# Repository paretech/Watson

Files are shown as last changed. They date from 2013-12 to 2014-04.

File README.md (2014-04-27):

Watson
======

Watson is a relatively simple RF power meter based on the "120 dB Measurement System" outlined in the Analog Devices (AD) AD8307 data sheet. Watson has a narrow and fixed measurement band centered on 10.7 MHz and was developed as the detector for a low cost spectrum analyzer design. 

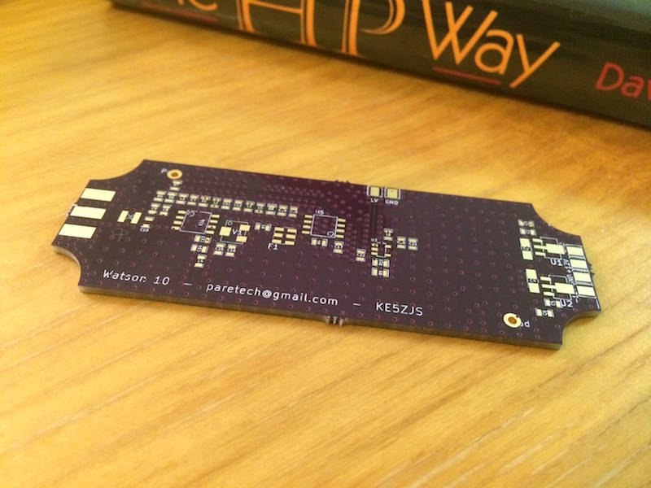
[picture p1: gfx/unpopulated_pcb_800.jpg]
Un-Populated Watson PCB


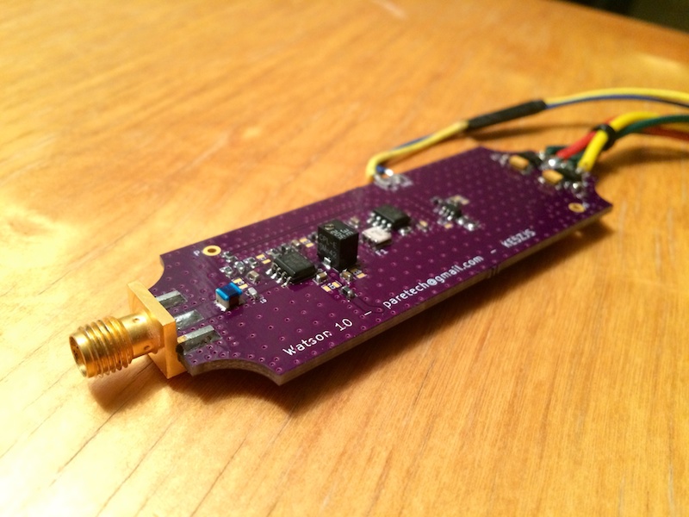
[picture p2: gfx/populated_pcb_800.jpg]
Populated Watson PCB


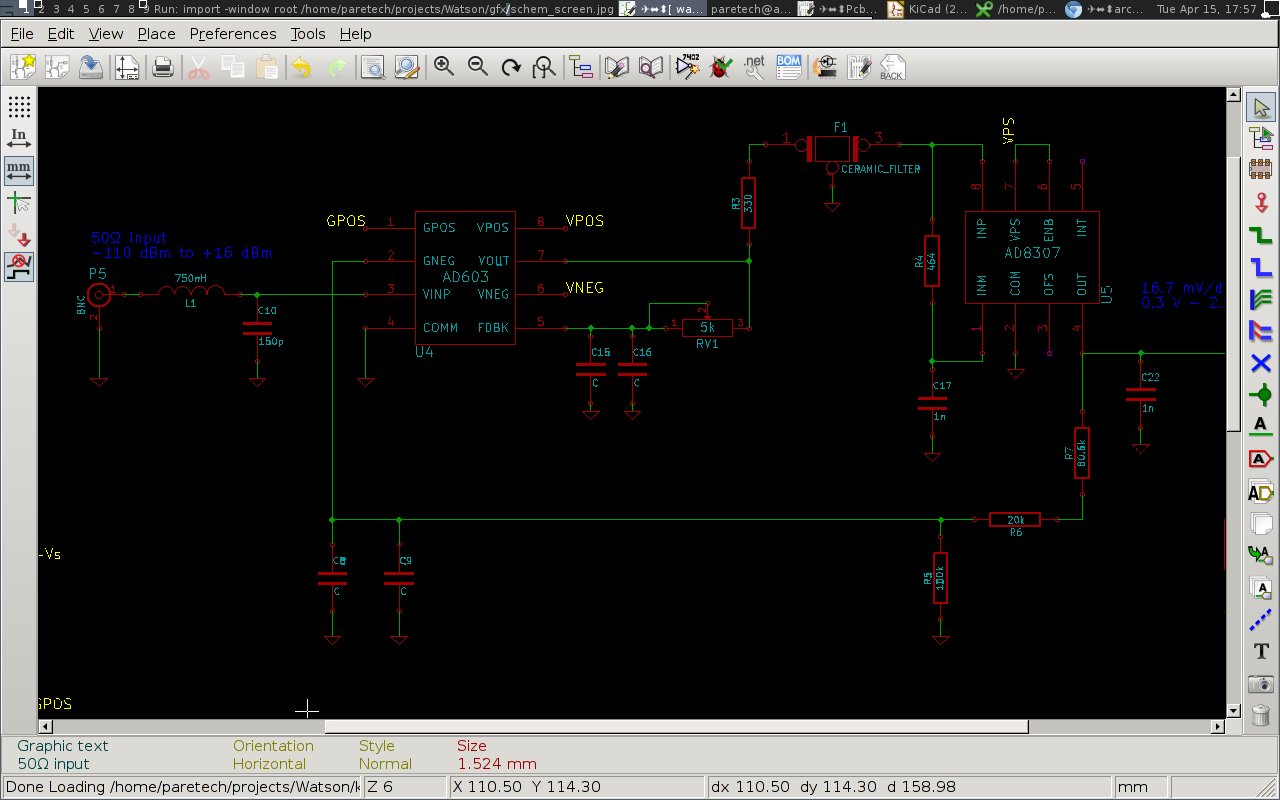
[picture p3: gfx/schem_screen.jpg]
Screen grab of Watson's Schematic


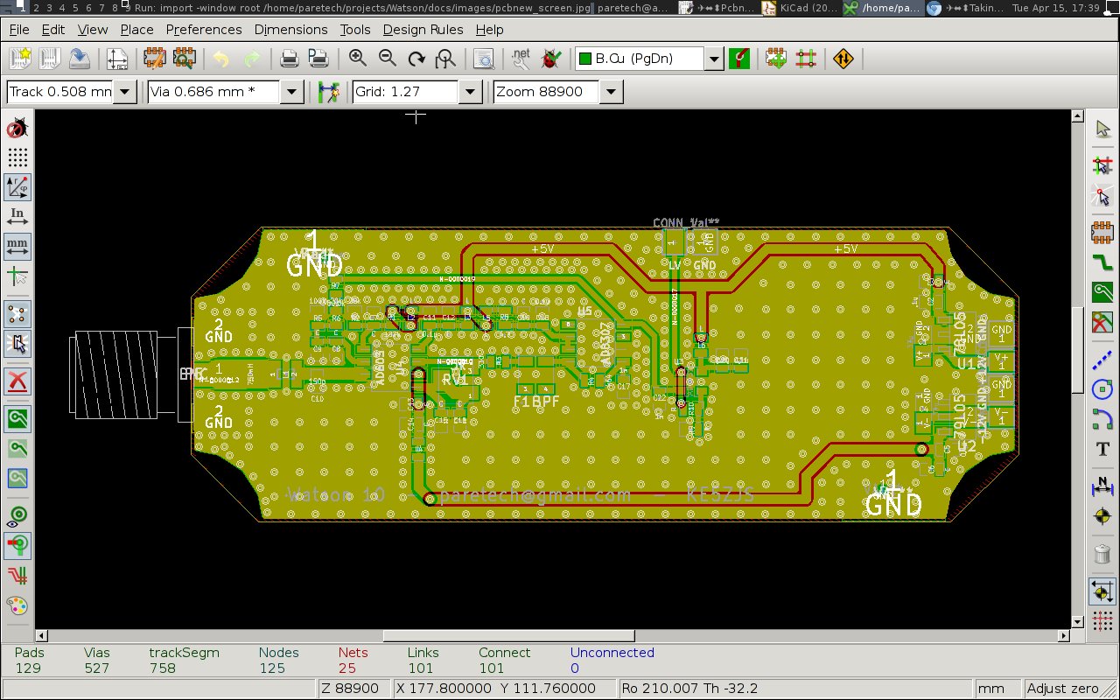
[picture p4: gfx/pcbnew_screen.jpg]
Snapshot of Watson's Board Layout


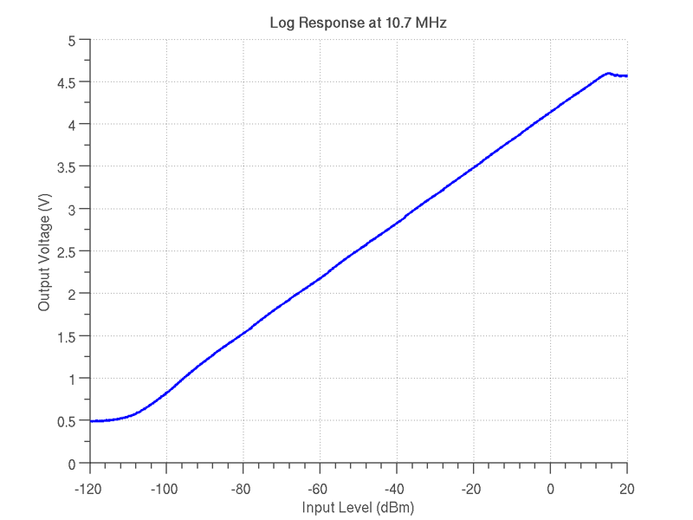
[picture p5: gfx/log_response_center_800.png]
Log Response at 10.7 MHz


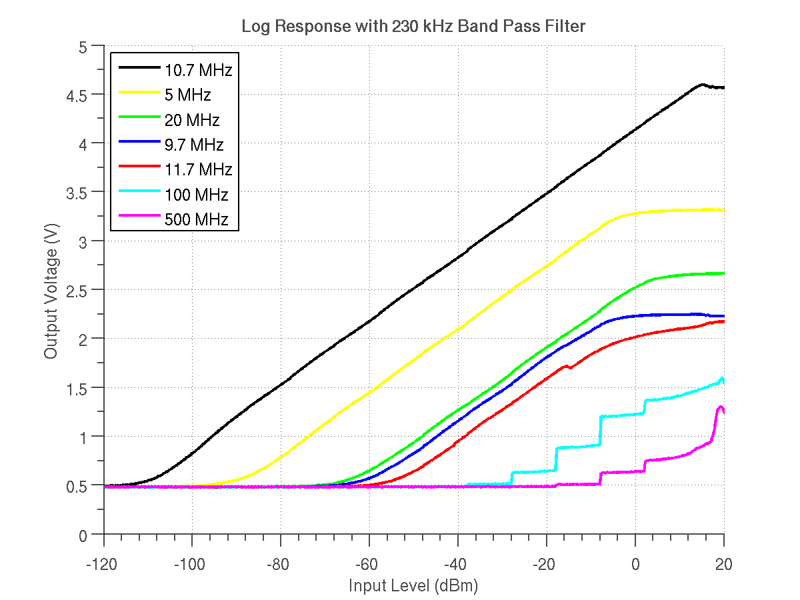
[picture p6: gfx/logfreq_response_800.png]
Log Frequency Response


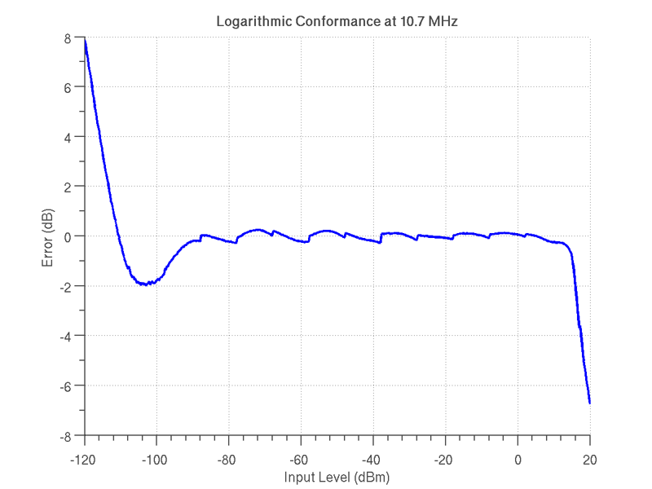
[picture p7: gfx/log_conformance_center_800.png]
Log Conformance at 10.7 MHz


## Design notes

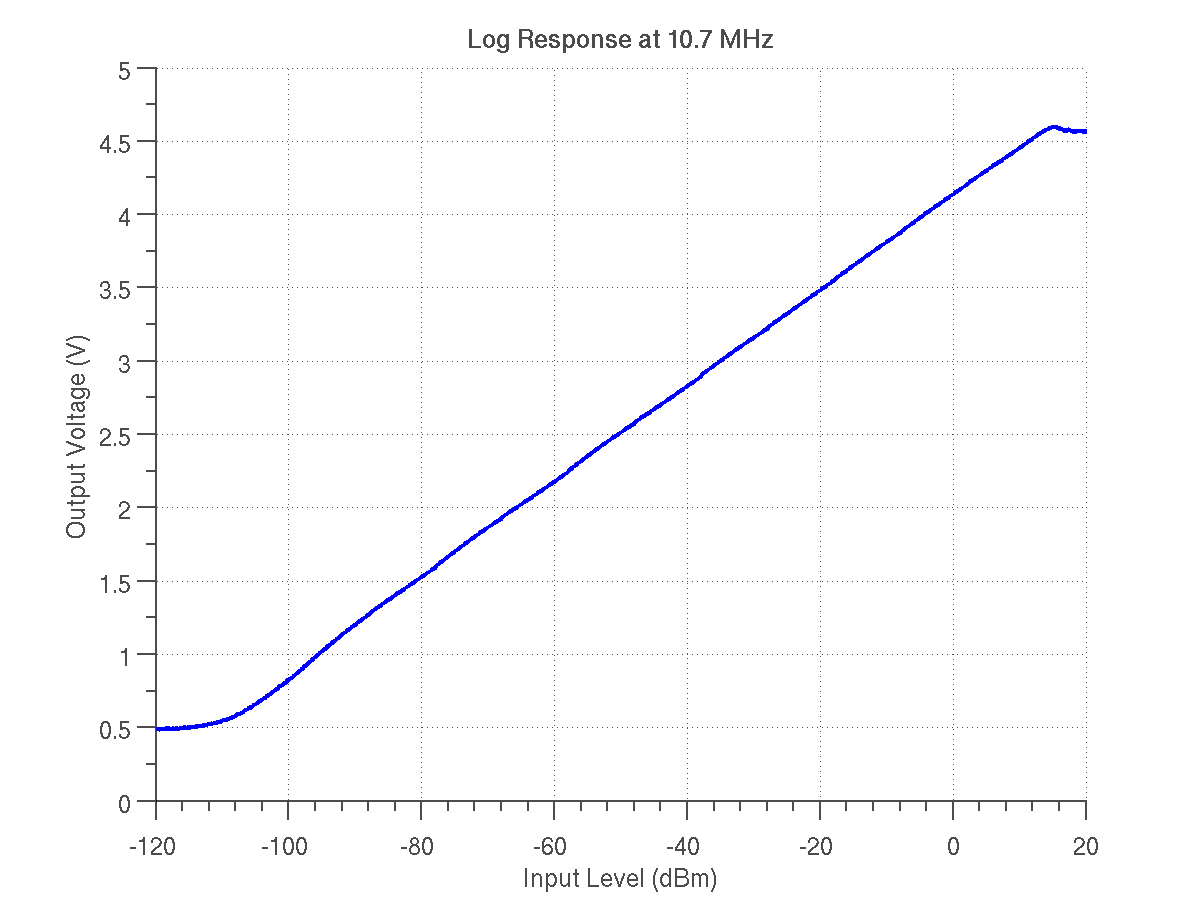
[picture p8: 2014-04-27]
gfx/log_response_center.png

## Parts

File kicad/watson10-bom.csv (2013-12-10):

Digi-Key Part Number | Manufacturer | Manufacturer Part Number | Quantity | Description | Reference
490-4681-1-ND | MURATA ELECTRONICS (VA) | SFECF10M7GA00-R0 | 1 | FILTER 10.7 MHZ 230 KHZ BAND SMD | F1
490-1229-1-ND | MURATA ELECTRONICS (VA) | SFECV10M7KA00-R0 | 0 | FILTER 10.7MHZ 110KHZ BANDWIDTH | F1 (alt)
J502-ND | EMERSON NETWORK POWER CONNECTIVITY JOHNSON | 142-0701-801 | 1 | CONN SMA JACK 50 OHM EDGE MNT | P5
490-5703-1-ND | MURATA ELECTRONICS (VA) | LQW2UASR75J00L | 1 | IND 750NH 360MA SRF 360MHZ 1008 | L1
AD603ARZ-ND | ANALOG DEVICES INC | AD603ARZ | 1 | IC OPAMP VGA 90MHZ 8SOIC | U4
AD8307ARZ-ND | ANALOG DEVICES INC | AD8307ARZ | 1 | IC LOGARITHMIC AMP 92DB 8-SOIC | U5
KA78L05AMTFCT-ND | FAIRCHILD SEMICONDUCTOR (VA) | KA78L05AMTF | 1 | IC REG LDO 5V 0.1A SOT89-3 | U1
KA79L05AMTFCT-ND | FAIRCHILD SEMICONDUCTOR (VA) | KA79L05AMTF | 1 | IC REG LDO -5V 0.1A SOT89-3 | U2
495-1497-1-ND | KEMET (VA) | T498A334K035ZTE11K | 2 | CAP TANT 0.33UF 35V 10% 1206 | C1, C4
SM-42TW502CT-ND | COPAL ELECTRONICS INC (VA) | SM-42TW502 | 1 | TRIMMER 5K OHM 0.25W SMD | RV1
HM182-ND | HAMMOND MANUFACTURING | 1550Z102 | 1 | BOX ALUM 3.55X1.43X1.20" UNPTD
490-5216-1-ND | MURATA ELECTRONICS (VA) | BLM18HE152SN1D | 20 | FERRITE CHIP 1500 OHM 500MA 0603 | L2, L3, L4, L5, L6
445-7031-1-ND | TDK CORPORATION (VA) | C1608C0G1H151F080AA | 1 | CAP CER 150PF 50V 1% NP0 0603 | C10
445-7318-1-ND | TDK CORPORATION (VA) | C0603X5R1A104K030BC | 100 | CAP CER 0.1UF 10V 10% X5R 0201
1276-4604-1-ND | SAMSUNG ELECTRO-MECHANICS AMERICA, INC (VA) | RC1608F331CS | 10 | RES 330 OHM 1/10W 1% 0603
1276-1018-1-ND | SAMSUNG ELECTRO-MECHANICS AMERICA, INC (VA) | CL10B102KB8NNNC | 100 | CAP CER 1000PF 50V 10% X7R 0603
1276-4618-1-ND | SAMSUNG ELECTRO-MECHANICS AMERICA, INC (VA) | RC1608F4640CS | 10 | RES 464 OHM 1/10W 1% 0603
1276-4861-1-ND | SAMSUNG ELECTRO-MECHANICS AMERICA, INC (VA) | RC1608F1873CS | 10 | RES 187K OHM 1/10W 1% 0603
1276-4783-1-ND | SAMSUNG ELECTRO-MECHANICS AMERICA, INC (VA) | RC1608F2802CS | 10 | RES 28K OHM 1/10W 1% 0603
1276-4486-1-ND | SAMSUNG ELECTRO-MECHANICS AMERICA, INC (VA) | RC1608F4R7CS | 10 | RES 4.7 OHM 1/10W 1% 0603
1276-3486-1-ND | SAMSUNG ELECTRO-MECHANICS AMERICA, INC (VA) | RC1608F104CS | 20 | RES 100K OHM 1/10W 1% 0603
1276-4768-1-ND | SAMSUNG ELECTRO-MECHANICS AMERICA, INC (VA) | RC1608F203CS | 20 | RES 20K OHM 1/10W 1% 0603
1276-4830-1-ND | SAMSUNG ELECTRO-MECHANICS AMERICA, INC (VA) | RC1608F8062CS | 10 | RES 80.6K OHM 1/10W 1% 0603
490-5219-1-ND | MURATA ELECTRONICS (VA) | BLM18HK102SN1D | 20 | FERRITE CHIP 1000 OHM 50MA 0603

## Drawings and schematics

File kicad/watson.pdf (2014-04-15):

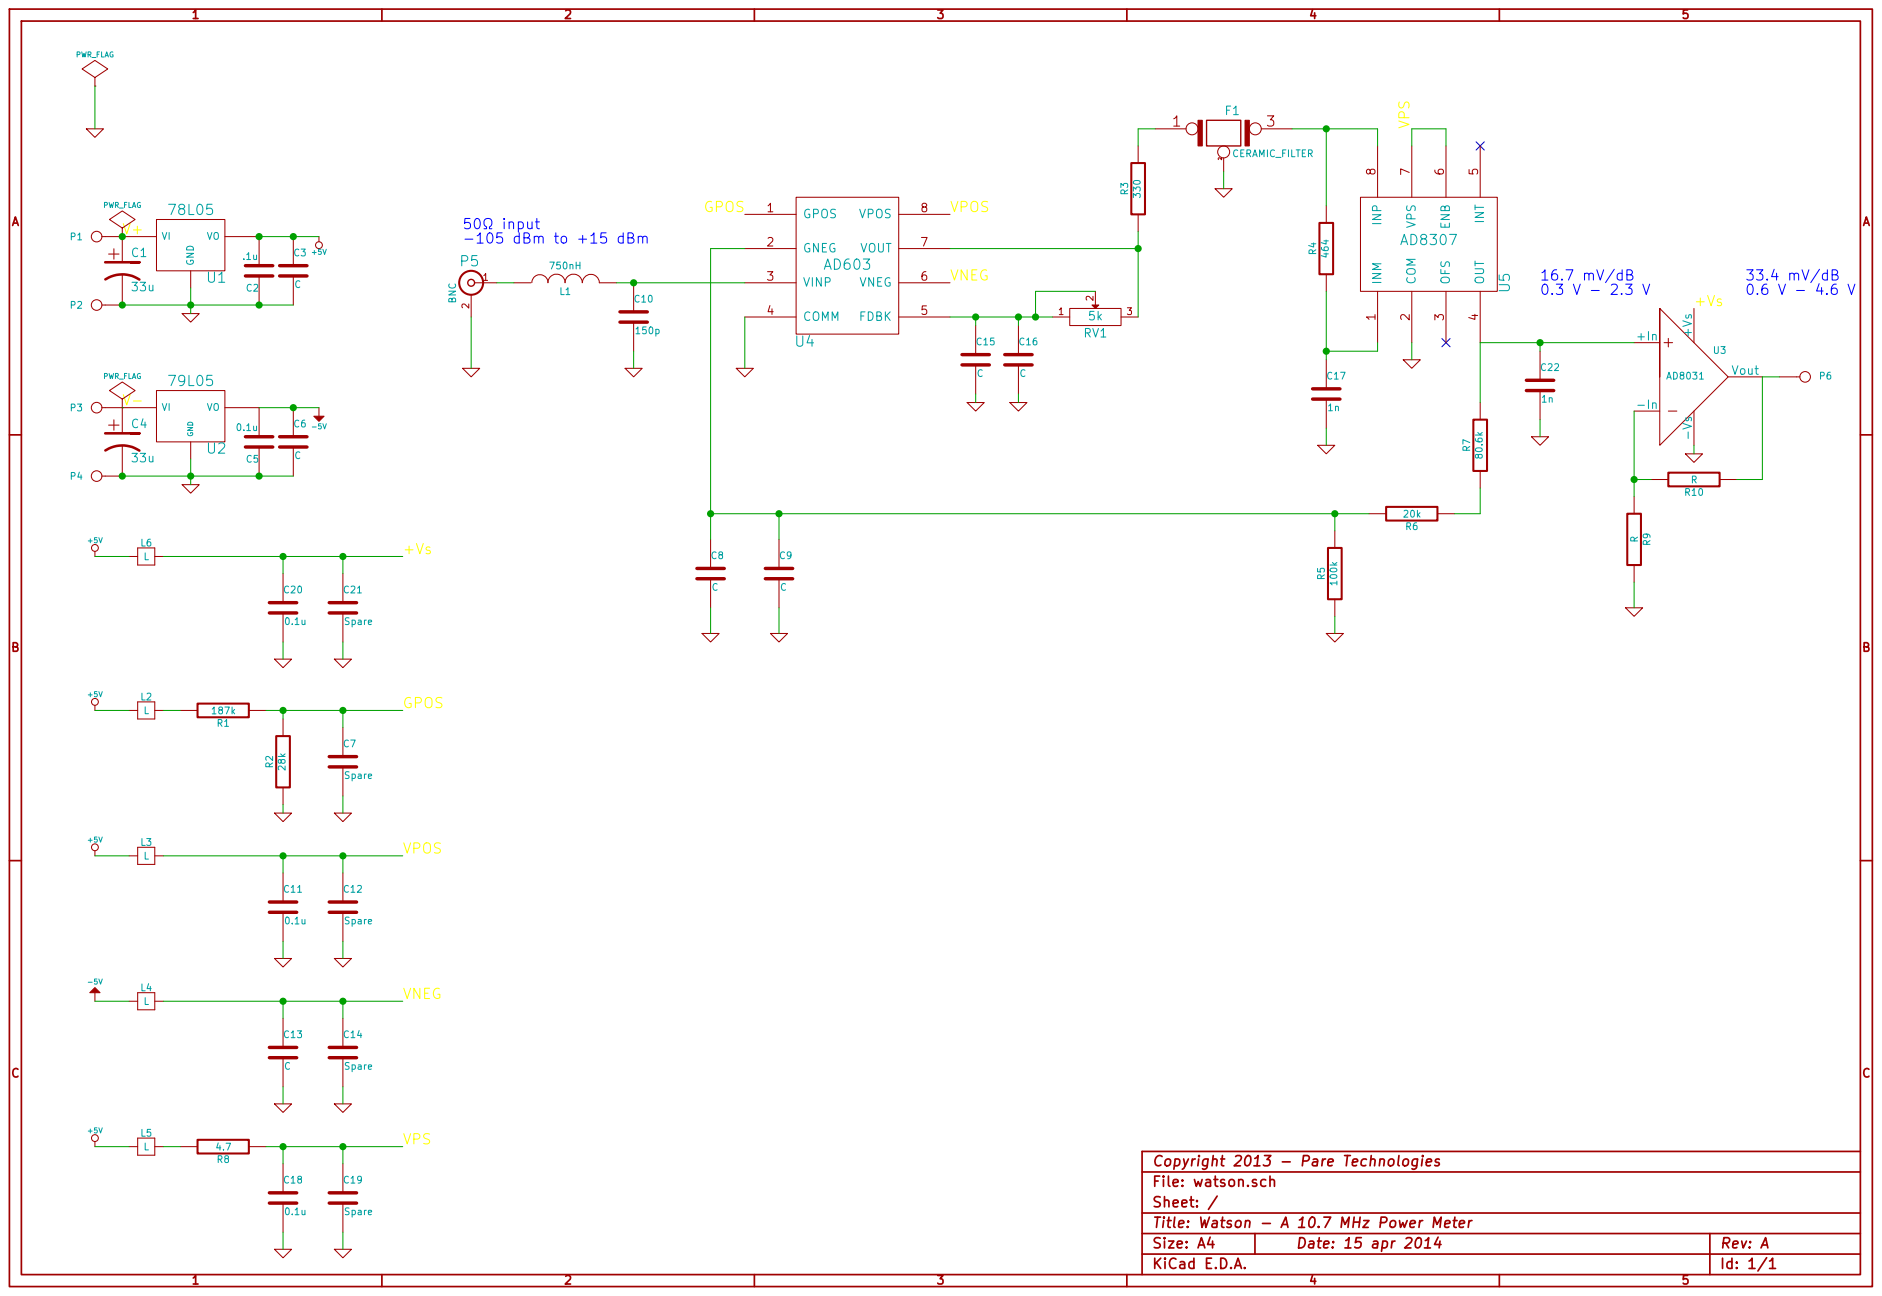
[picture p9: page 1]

C9C 50 input -105 dBm to +15 dBm

Copyright 2013 - Pare Technologies
Id: 1/1 Title: Watson - A 10.7 MHz Power Meter File: watson.sch Sheet: /

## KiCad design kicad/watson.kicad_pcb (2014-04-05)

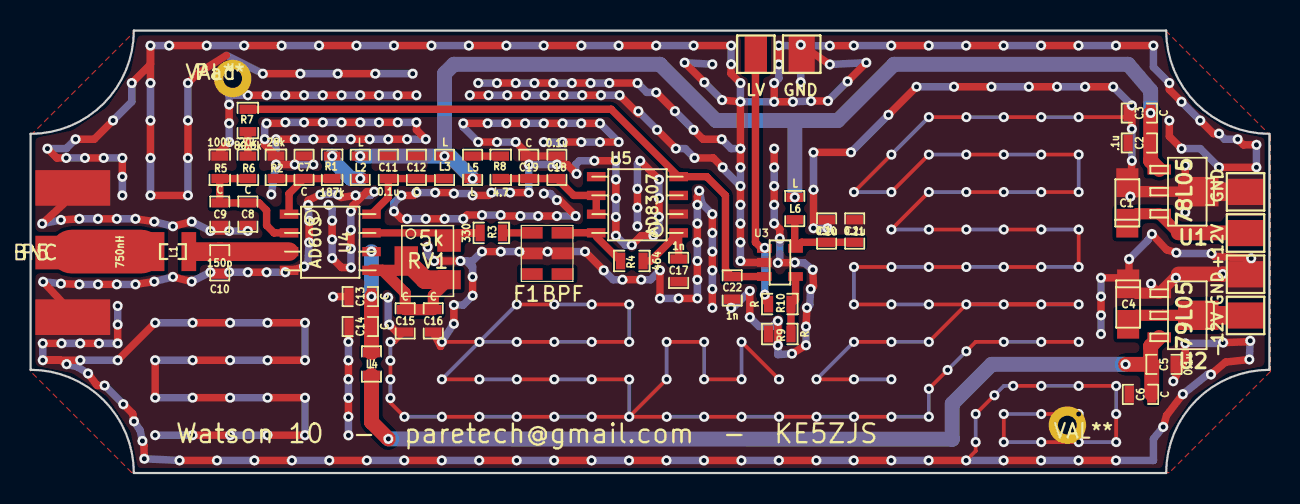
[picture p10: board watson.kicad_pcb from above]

Board: 2 copper layers, 84.0 x 30.0 mm, 54 parts (0 on the bottom side), 24 nets.

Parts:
+12V: CONN_1; PIN_ARRAY_1
-12V: CONN_1; PIN_ARRAY_1
C1, C4: 33u; c_tant_A
C2: .1u; SM0603_Capa
C3, C6, C7, C8, C9, C12, C13, C14, C15, C16, C19: C; SM0603_Capa
C5, C11, C18, C20, C21: 0.1u; SM0603_Capa
C10: 150p; SM0603_Capa
C17, C22: 1n; SM0603_Capa
F1: BPF; SFEC
GND: CONN_1; PIN_ARRAY_1
GND#2: CONN_1; PIN_ARRAY_1
GND#3: Val**; PIN_ARRAY_1
L1: 750nH; 180mm_ChipCoil
L2, L3, L4, L5, L6: L; SM0603_Inductor
LV: CONN_1; PIN_ARRAY_1
P5: BNC; sma-edge-062
Pad: VAL**; Pad
R1: 187k; SM0603_Resistor
R2: 28k; SM0603_Resistor
R3: 330; SM0603_Resistor
R4: 464; SM0603_Resistor
R5: 100k; SM0603_Resistor
R6: 20k; SM0603_Resistor
R7: 80.6k; SM0603_Resistor
R8: 4.7; SM0603_Resistor
R9, R10: R; SM0603_Resistor
RV1: 5k; VRSM3932_JHOOK
U1: 78L05; sot89
U2: 79L05; sot89
U3: AD8031; sot23
U4: AD603; so-8
U5: AD8307
hole: VAL**; hole

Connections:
+5V: C2.2, C3.1, L2.1, L3.1, L5.1, L6.1, U1.1
-5V: C5.2, C6.1, L4.1, U2.3
/+Vs: C20.1, C21.1, L6.2, U3.5
/GPOS: C7.1, R1.1, R2.2, U4.1
/V+: +12V.1, C1.1, U1.3
/V-: -12V.1, C4.1, U2.2
/VNEG: C13.1, C14.1, L4.2, U4.6
/VPOS: C11.1, C12.1, L3.2, U4.8
/VPS: C18.2, C19.2, R8.1, U5.6, U5.7
GND: C1.2, C2.1, C3.2, C4.1, C5.1, C6.2, C7.2, C8.2, C9.2, C10.2, C11.2, C12.2, C13.2, C14.2, C15.2, C16.2, C17.2, C18.1, C19.1, C20.2, C21.2, C22.2, F1.2, F1.5, GND.1, GND#2.1, GND#3.1, P5.2, Pad.1, R2.1, R5.1, R9.2, U1.2, U2.1, U3.2, U4.4, U5.2, hole.1
unnamed: R6.1, R7.1
unnamed: C17.1, R4.1, U5.1
unnamed: F1.6, R4.2, U5.8
unnamed: C8.1, C9.1, R5.2, R6.2, U4.2
unnamed: F1.1, R3.2
unnamed: R3.1, RV1.3, U4.7
unnamed: C15.1, C16.1, RV1.1, RV1.2, U4.5
unnamed: L1.1, P5.1
unnamed: LV.1, R10.1, U3.1
unnamed: R9.1, R10.2, U3.4
unnamed: C22.1, R7.2, U3.3, U5.4
unnamed: L2.2, R1.2
unnamed: L5.2, R8.2
unnamed: C10.1, L1.2, U4.3

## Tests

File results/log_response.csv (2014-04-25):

NaN | 5e+05 | 1e+06 | 5e+06 | 9.7e+06 | 1.07e+07 | 1.17e+07 | 2e+07 | 1e+08 | 5e+08
-120 | 0.47775 | 0.47851 | 0.47902 | 0.48083 | 0.4876 | 0.48026 | 0.47613 | 0.47783 | 0.48103
-119.75 | 0.47969 | 0.48079 | 0.47875 | 0.48001 | 0.49017 | 0.48234 | 0.48016 | 0.48084 | 0.4823
-119.5 | 0.47634 | 0.47781 | 0.47812 | 0.48213 | 0.48656 | 0.48303 | 0.47997 | 0.48178 | 0.48229
-119.25 | 0.47722 | 0.47919 | 0.47953 | 0.47986 | 0.49155 | 0.47854 | 0.47812 | 0.47743 | 0.48119
-119 | 0.47946 | 0.47725 | 0.47969 | 0.47926 | 0.48876 | 0.48278 | 0.47906 | 0.48223 | 0.48028
-118.75 | 0.47954 | 0.48202 | 0.48103 | 0.47911 | 0.49005 | 0.48238 | 0.47767 | 0.48072 | 0.48233
-118.5 | 0.47851 | 0.47856 | 0.48102 | 0.48085 | 0.4926 | 0.48398 | 0.47909 | 0.4794 | 0.48058
-118.25 | 0.47609 | 0.48367 | 0.47872 | 0.47959 | 0.49276 | 0.48013 | 0.47891 | 0.48166 | 0.47874
-118 | 0.47861 | 0.47799 | 0.47847 | 0.47889 | 0.4921 | 0.4798 | 0.47561 | 0.47875 | 0.48077
-117.75 | 0.47889 | 0.47963 | 0.47925 | 0.48097 | 0.4904 | 0.48392 | 0.47738 | 0.47792 | 0.48
-117.5 | 0.48122 | 0.4793 | 0.47823 | 0.47645 | 0.49223 | 0.47752 | 0.47851 | 0.48109 | 0.4812
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

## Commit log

2013-09-21 Schematic, schematic library, partial footprint.
    [watson.sch]
2013-09-21 Renumbered components in schematic and added capacitors to module file.
    [watson.sch]
2013-09-22 Updated module library to include foot prints for edge mount SMA, 0603 resistor and 0603 capacitor.
2013-09-22 Schematic reworked.
    [watson.sch]
2013-09-24 Added ferrite bead module and created an autoplace PCB.
    [watson.kicad_pcb, watson.sch]
2013-09-25 Added footprints SOT89, c_tant_A, AD8307; Added new footprint parts to pcb.
    [watson.kicad_pcb]
2013-09-26 Added chip coil layout
    [watson.kicad_pcb]
2013-09-30 Added AD8031 to buffer output of AD8307.
    [watson.kicad_pcb, watson.sch]
2013-10-01 add image of Watson's schematic
2013-10-01 Added cover image for Watson's board layout
2013-12-10 This is the initial manufactured version of Watson, Watson 10 to be exact.
    [watson.kicad_pcb, watson.sch]
2013-12-10 Added CSV Bom
    [watson10-bom.csv]
2014-04-02 I'm a terrible committer. I think these are the latest files that I actually sent to OSH Park... I hope....
    [watson.kicad_pcb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]
2014-04-05 Deleted grid_origin (line 68) for Arch Linux backwards compatibility with stable community release 2013-05-18 BZR4017
    [watson.kicad_pcb]
2014-04-11 Added updated measurement data, scripts to generate plots and generated plots. Removed pdf schematic because it was outdated.
    [log_response.csv]
2014-04-15 Reorganized repo and added a few images and pdf schematic.
    [log_response.csv, watson.kicad_pcb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]
2014-04-19 Added 4 new images of populated and unpopulated PCB in 2 different sizes each
2014-04-25 Added new CSV file containing 9 frequency sweeps. First row and column of csv file contains the frequency and power information. Updated existing graph scripts to use new file. No new graphs added ye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
    [log_response.csv]
